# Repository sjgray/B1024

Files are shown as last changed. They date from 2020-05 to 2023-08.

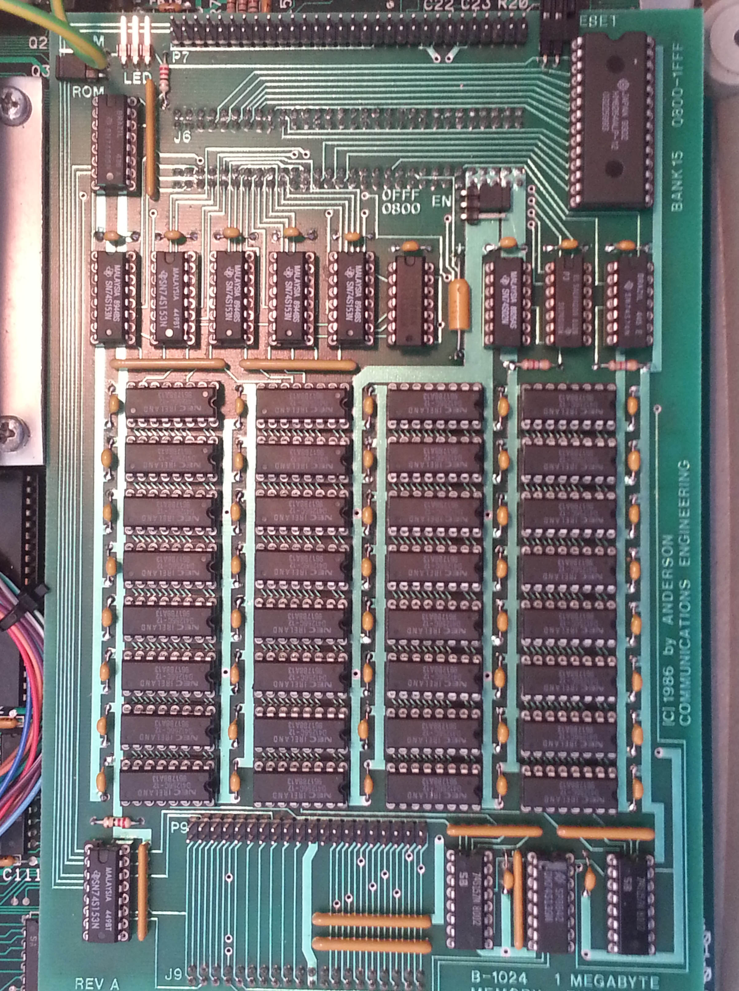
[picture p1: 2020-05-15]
board pics/B1024-Installed.jpg

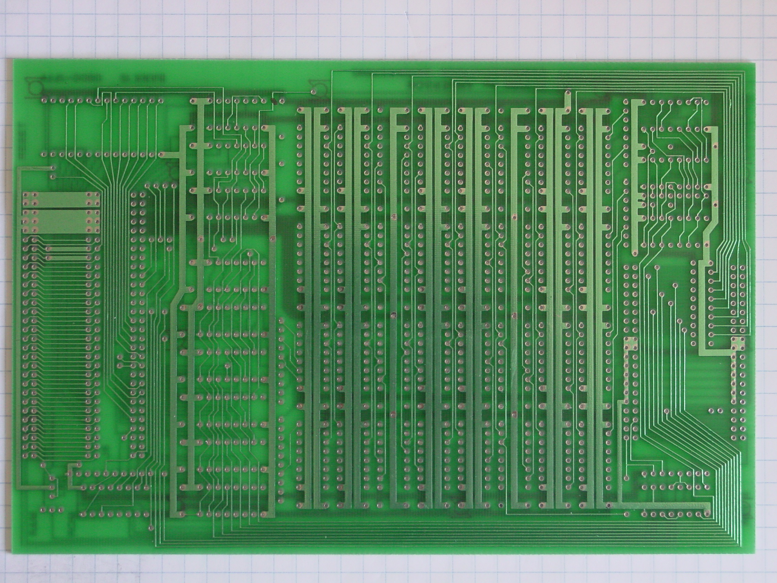
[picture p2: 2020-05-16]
board pics/B1024-Bare-Bottom-mirrored.jpg

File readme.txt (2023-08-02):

B1024 Clone Project (C)2020 Steve J. Gray.
=================== Started May 2020. Updated Aug 2023.

OVERALL STATUS: In Progress

SCHEMATICS    : Currently Reverse engineering Schematic diagram.
BOARD LAYOUT  : Mostly complete
BOARD LABELS  : NONE
GERBERS       : NONE
PCB           : NONE

Intro
-----

This is a project to clone the
Anderson Communication Engineering 1024K Board (Rev A) for CBM-II.

Mike Naberezny purchased a bare board from Bill Degnan and
then scanned it and posted pictures on his web page:

http://mikenaberezny.com/hardware/cbm-ii/b1024-ram-expansion-board/

Thank-you to Mike for providing this information!

Component Reference
-------------------

Since the board has no references for the IC's
I have numbered them based on the following:

- With the board oriented with pin 1's on the LEFT or TOP.
- U1 is at the top left.
- Connectors P7 and J6 are below it
- U2 is at the bottom left.
- U3 to U12 are to the right.

The DRAMs are:
- U12 to U19 on the top row
- U29 to U27
- U28 to U35
- U36 to U43 on the bottom row

Then U44 to U47 on the right of the board
P9 and J9 are between U46 and U47

PARTS LIST
==========

Sockets:
--------
  - 28 pin x 1 for 6264
  - 16 pin x32 for DRAMs
  - 16 pin x11 for other chips
  - 14 pin x 3 for other chips

ICs:
----
U1 - 6264 SRAM, 8Kx8
U2 - 74S85   4-bit Comparator
U3 - 74S74   Dual D positive edge Flip-Flop
U4 - 74S08   Quad 2-input AND
U5 - 74S02   Quad 2-input NOR
U6 - 74LS393 Dual 4-bit Binary Counter
U7 - 74S153  Dual 4 to 1 selector
U8 - 74S153  Dual 4 to 1 selector
U9 - 74S153  Dual 4 to 1 selector
U10- 74S153  Dual 4 to 1 selector
U11- 74S153  Dual 4 to 1 selector

U12 to U43 - 41256 DRAM 256Kx1

U44- 74S157  Quad 2 to 1 Multiplexer
U45- 74S139  Dual 2 to 4 line decoder
U46- 74S157  Quad 2 to 1 Multiplexer
U47- 74S153  Dual 4 to 1 selector

Capacitors:
-----------
C1 to C51 - 0.1uf disc

Resistors:
----------
R1        - 22 ohm
R2, R3    - 4.7K
R4        - 22 ohm

RN1 - 4.7K   SIP 10-pin Bussed   9 Resistor Network
RN2 - 22 ohm SIP 10-pin Separate 5 Resistor Pack
RN3 - 22 ohm SIP 10-pin Separate 5 Resistor Pack
RN4 - 22 ohm SIP 8-pin  Separate 4 Resistor Pack
RN5 - 22 ohm SIP 8-pin  Separate 4 Resistor Pack
RN6 - 4.7K   SIP 8-pin  Bussed   7 Resistor Network
RN7 - 10K    SIP 10-pin Bussed   9 Resistor Network
RN8 - 10K    SIP 10-pin Bussed   9 Resistor Network
RN9 - 4.7K   SIP 8-pin  Bussed   7 Resistor Network

Jumpers/Headers:
----------------
J1 - 2-pin 90 degree male header "RESET" 
J2 - 3-pin 90 degree male header "0FFF/0800 EN"
J3 - 3-pin 90 degree male header "LED"
J4 - 3-pin 90 degree male header "RAM ROM" 
J5 - 60-pin vertical female header 
J6 - 60-pin vertical female header
J9 - 40-pin vertical female headerc
P7 - 60-pin vertical male header
P9 - 40-pin vertical male header

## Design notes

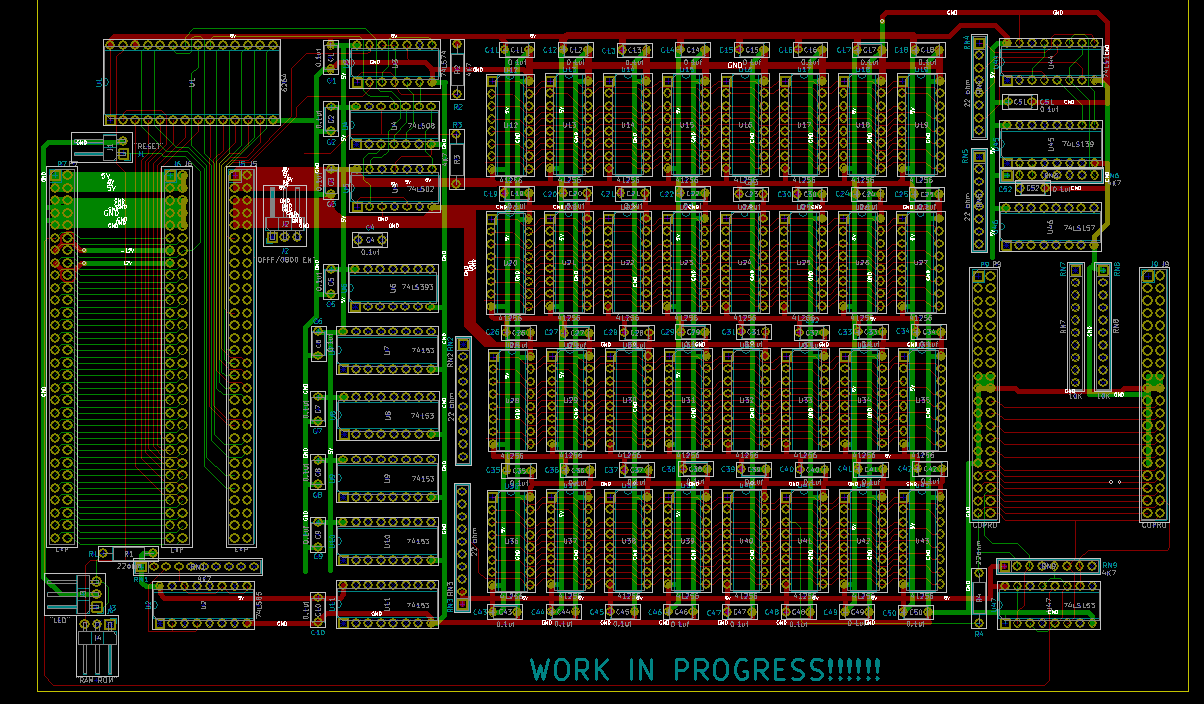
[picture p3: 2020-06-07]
B1024-Kicad Layout.png

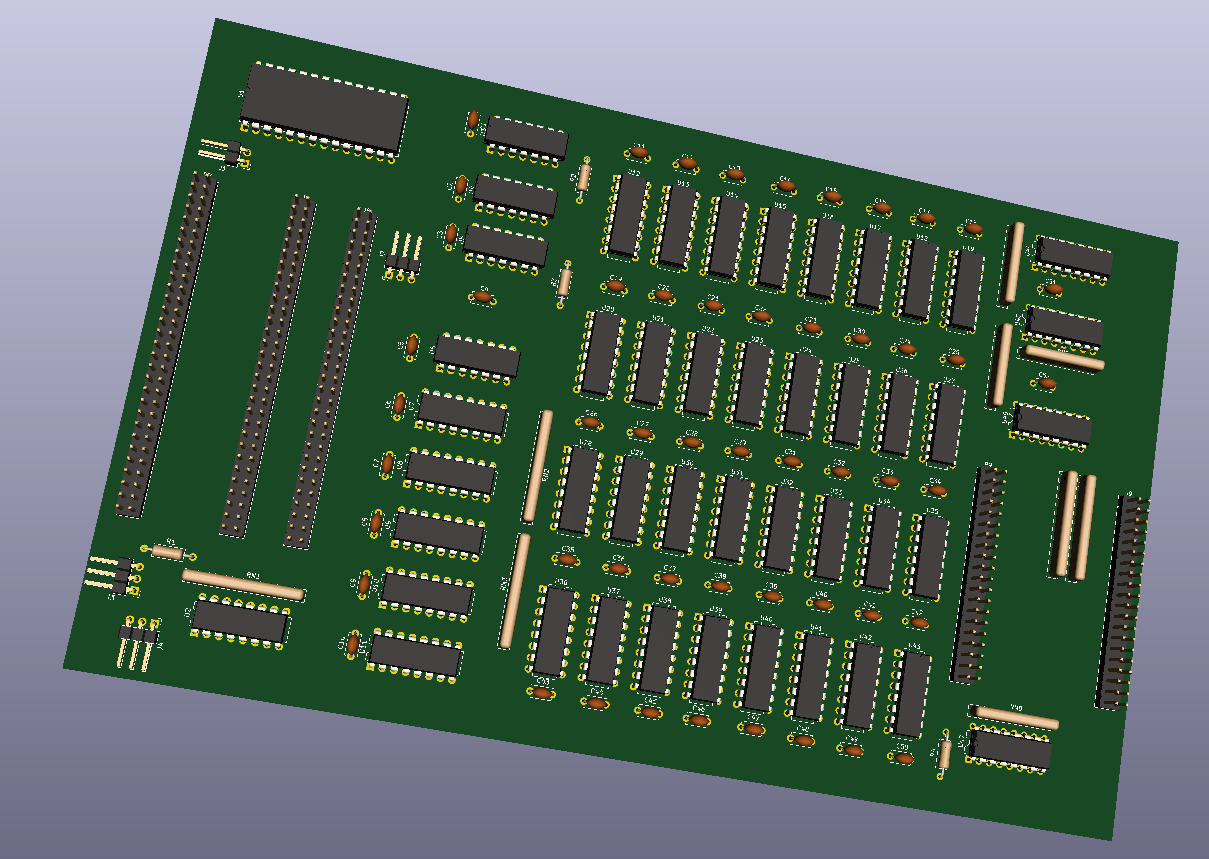
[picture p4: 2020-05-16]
B1024-Kicad Board.png

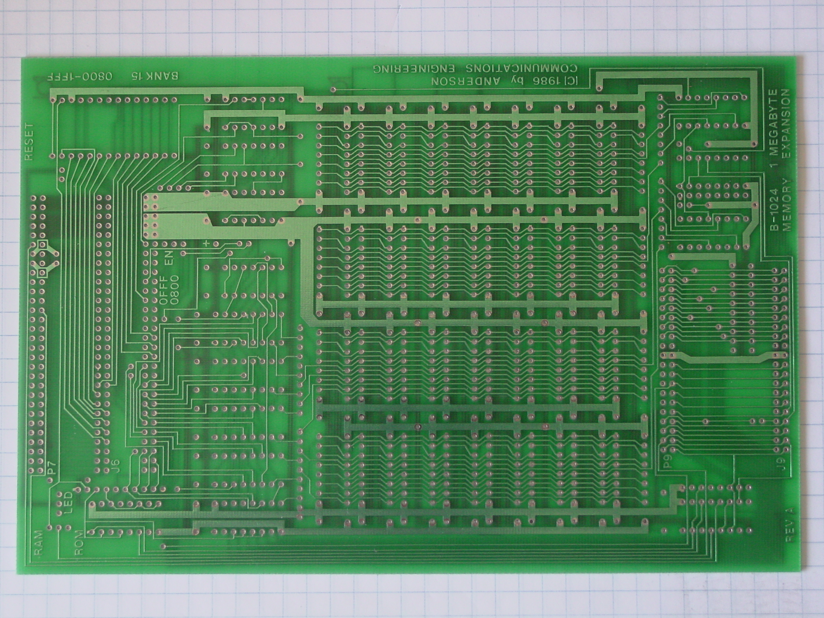
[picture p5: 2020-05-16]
board pics/B1024-Bare-Top.jpg

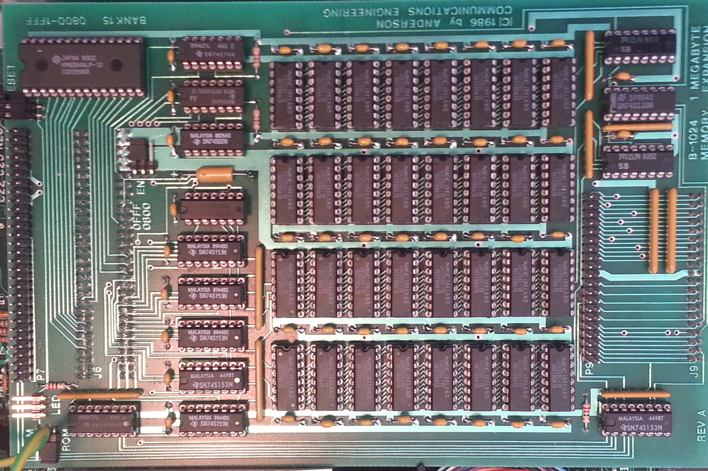
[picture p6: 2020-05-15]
board pics/B1024-Complete.jpg

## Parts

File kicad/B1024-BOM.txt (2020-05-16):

Anderson Communications Engineering B1024 Board for CBM-II
==========================================================
BOM

#01 Circuit Board
#09 Sockets 16-pin x32 for DRAMs
            16-pin x11 for other chips
            14-pin  x3 for other chips
#10 Socket 28-pin x1 for 6264
#11 (Not needed) DIP Plug
#12 Jumper  19141 0.12/ea minimum 10  DONE
#13 41256 DRAM x32  41398  0.69/ea for more than 10  DONE
#14 6264            42892  2.75 DONE
#15 74S02   48266   $0.69  DONE
#16 74S08   48303   $0.69  DONE
#17 74S74   676991  $0.79  DONE
#18 74S85   48952   $1.19  DONE
#19 74S139  ???            DONE
#20 74S153  ???            DONE
#21 74S157  48451   $1.25  DONE
#22 74LS393 47731   $0.85  DONE
#23 0.1uF x51 544921  minimum 10   $0.11 for 100+
#32 4.7K .25W

691024  4.7Kohm .25W
22 ohm 4 section / 8 pin  4608X-2-220LF-ND
22 ohm 5 section / 8 pin  4610X-2-220LF-ND
4.7K 7 section / 8 pin    4608X-1-472LF-ND
4.7K 9 section / 10 pin   4610X-1-472LF-ND
10K 9 section / 10 pin    4610X-1-103LF-ND
10-pin: 5
8-pin: 4

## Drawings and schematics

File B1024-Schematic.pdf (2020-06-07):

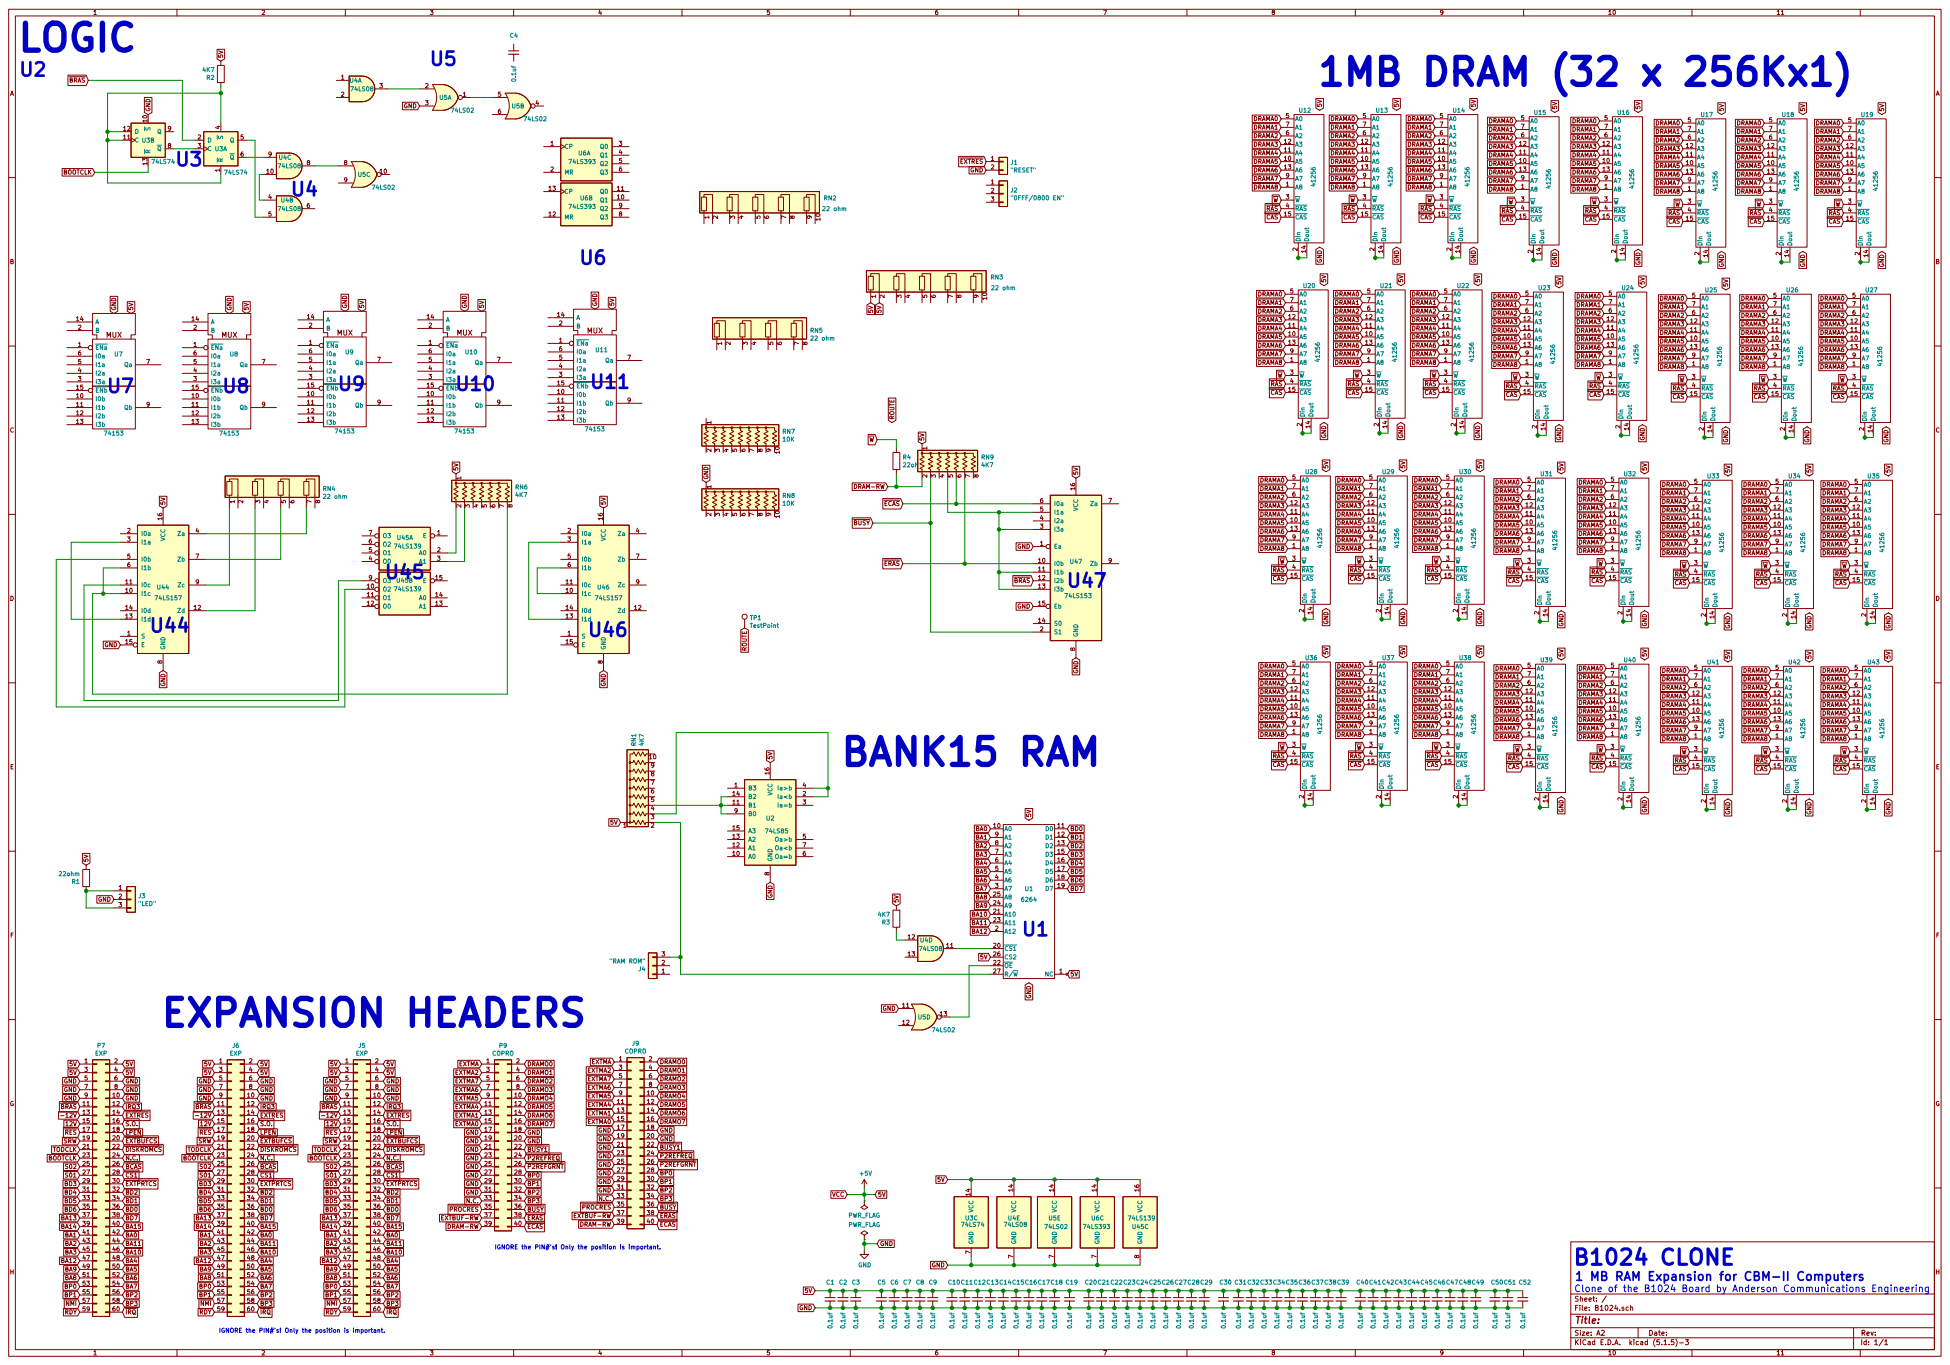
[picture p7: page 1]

DRAMA0 DRAMA1 DRAMA2 DRAMA3 DRAMA4 DRAMA5 DRAMA6 DRAMA7 DRAMA8 RAS CAS DRAMA0 DRAMA4 DRAMA5 DRAMA6 DRAMA7 DRAMA8 RAS CASW

IGNORE the PIN#'s! Only the position is important.

B1024 CLONE
1 MB RAM Expansion for CBM-II Computers
Clone of the B1024 Board by Anderson Communications Engineering

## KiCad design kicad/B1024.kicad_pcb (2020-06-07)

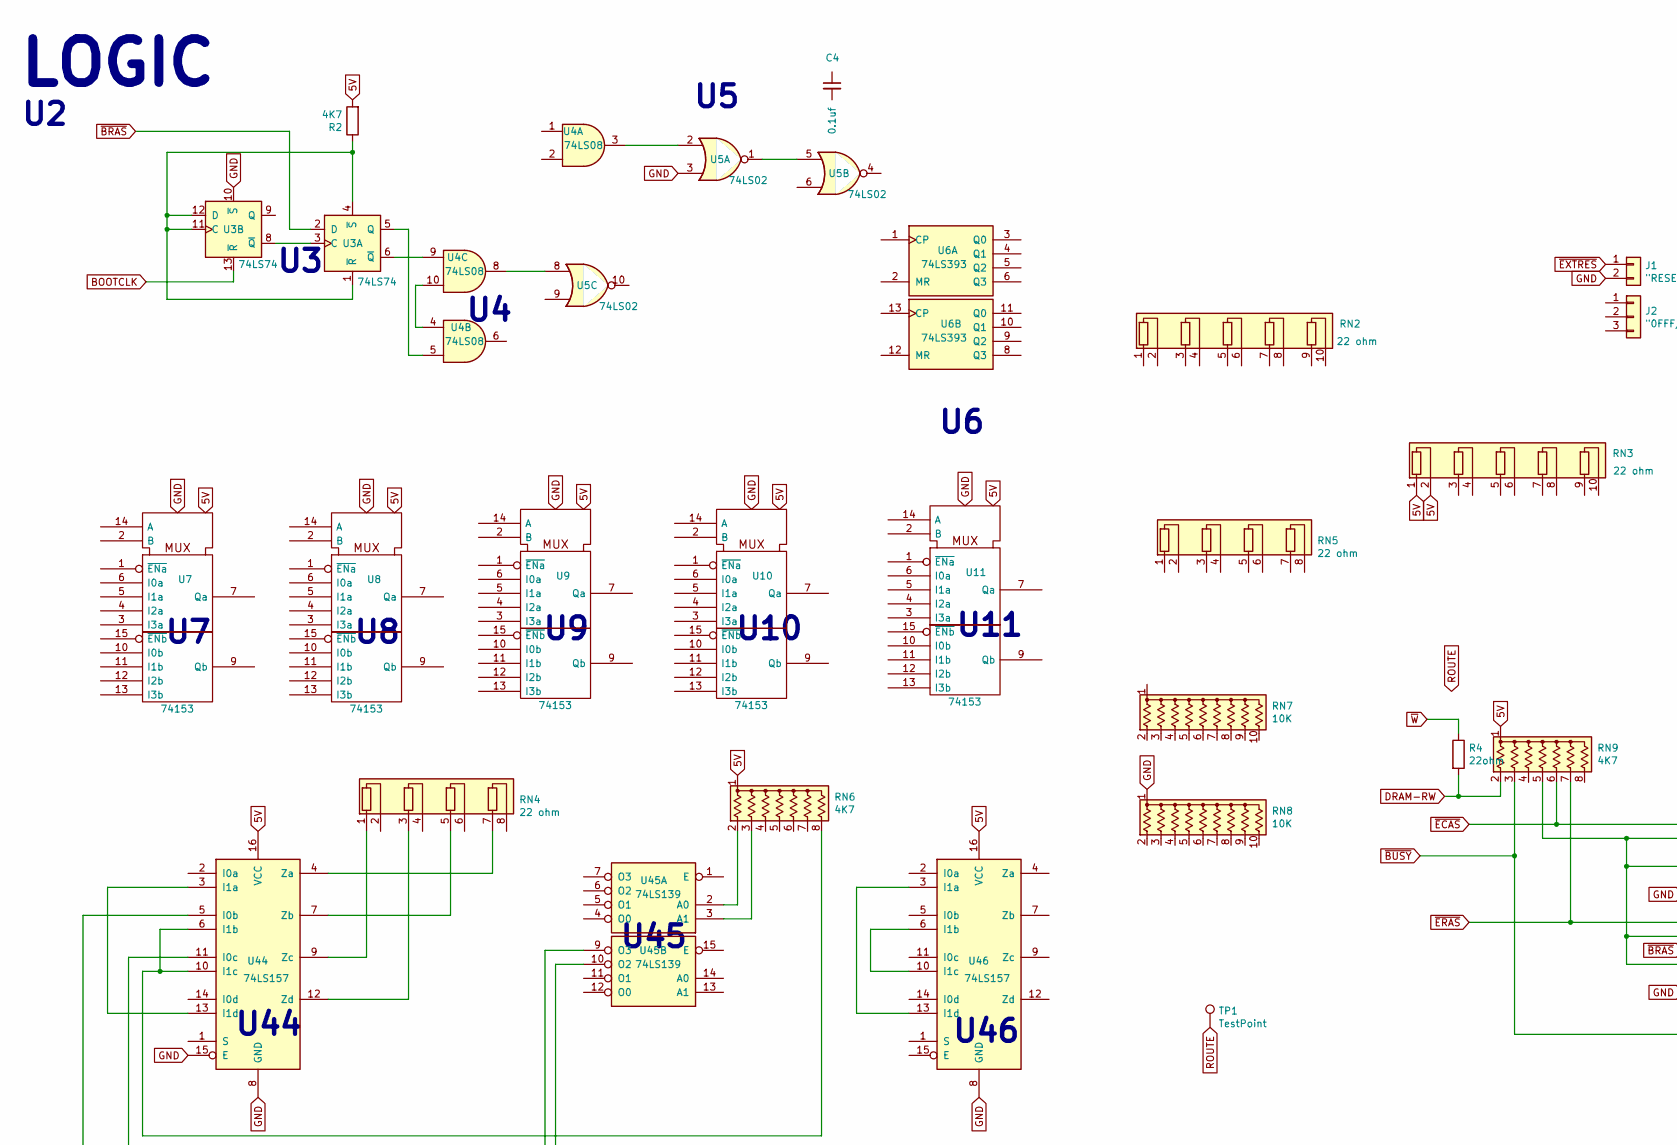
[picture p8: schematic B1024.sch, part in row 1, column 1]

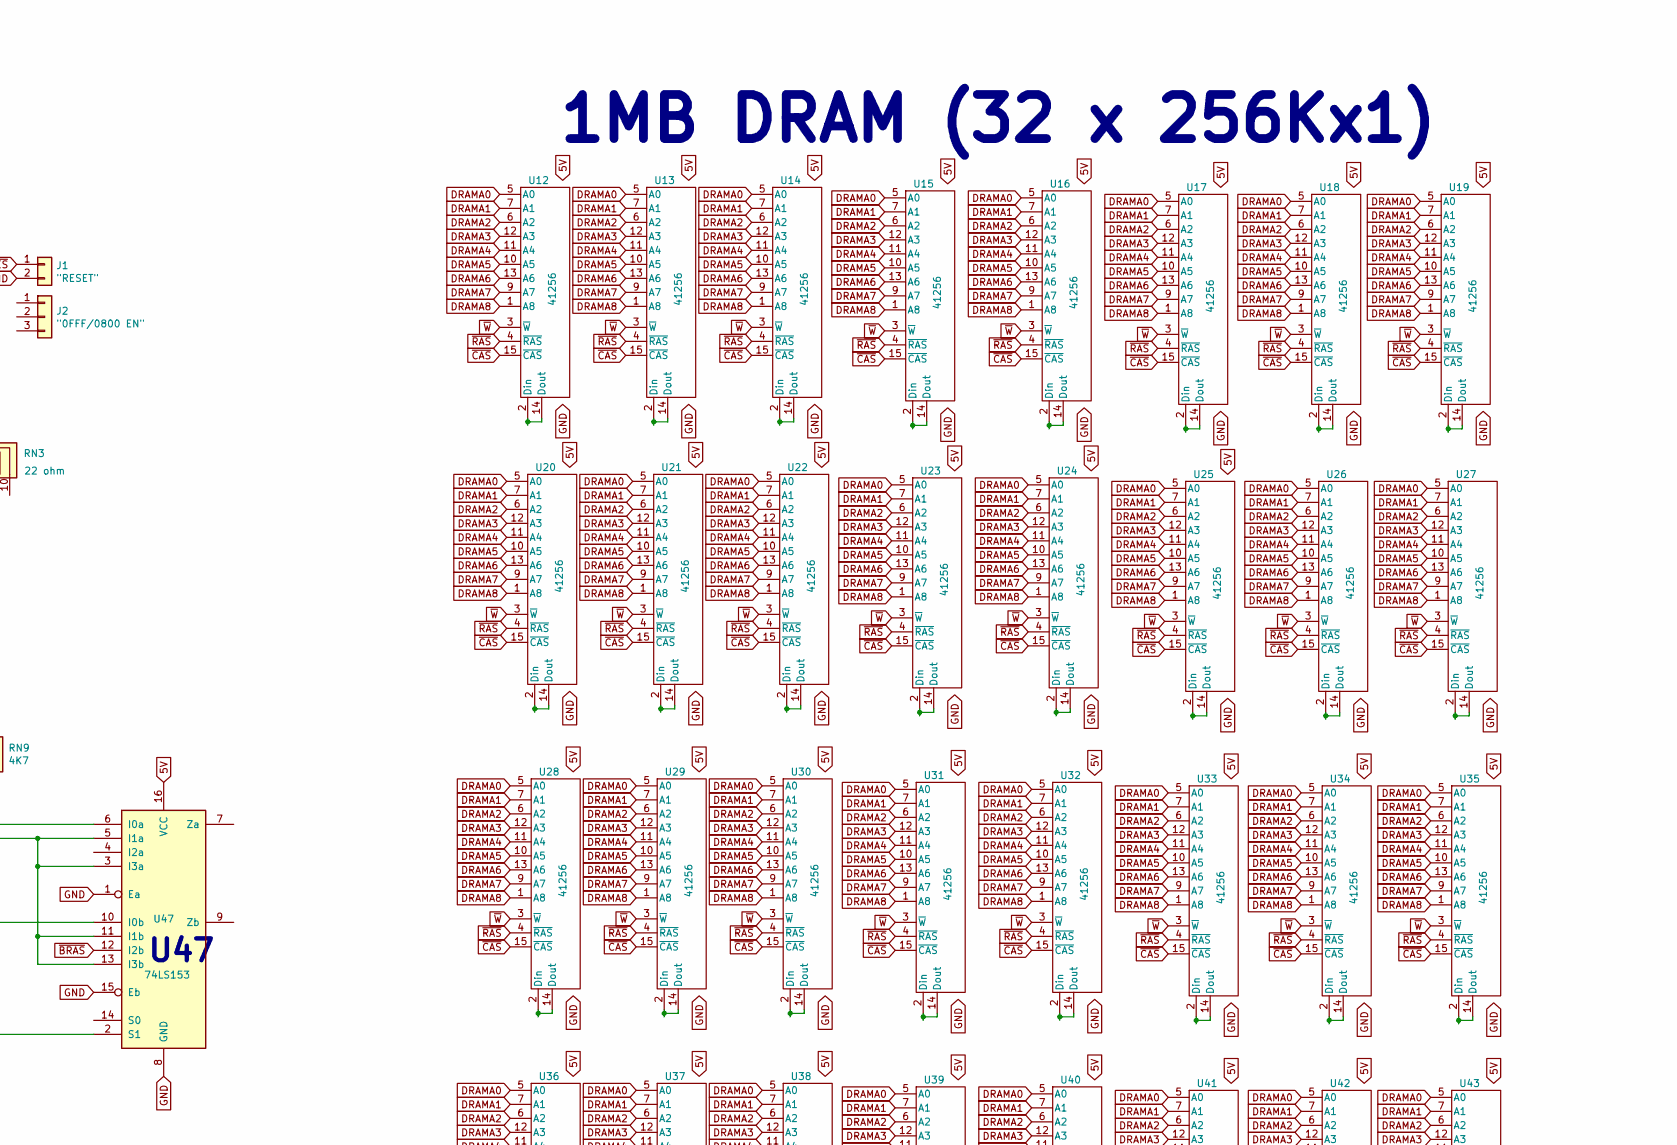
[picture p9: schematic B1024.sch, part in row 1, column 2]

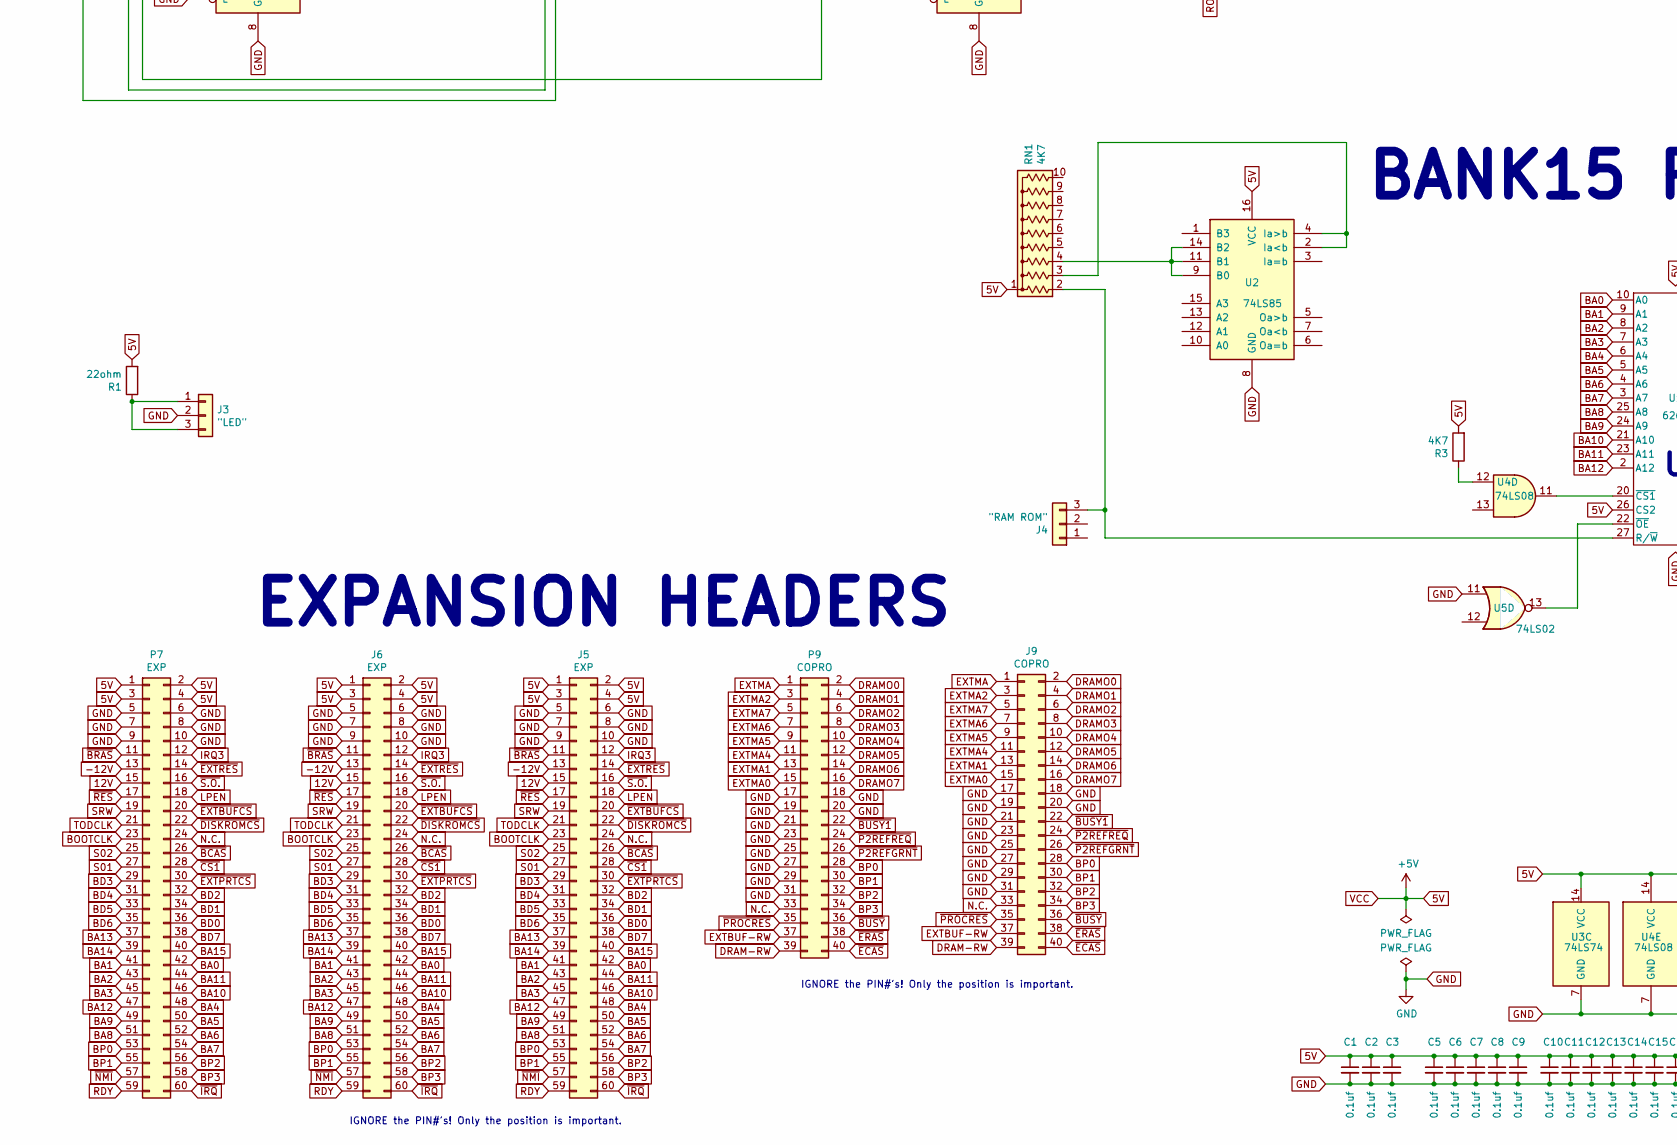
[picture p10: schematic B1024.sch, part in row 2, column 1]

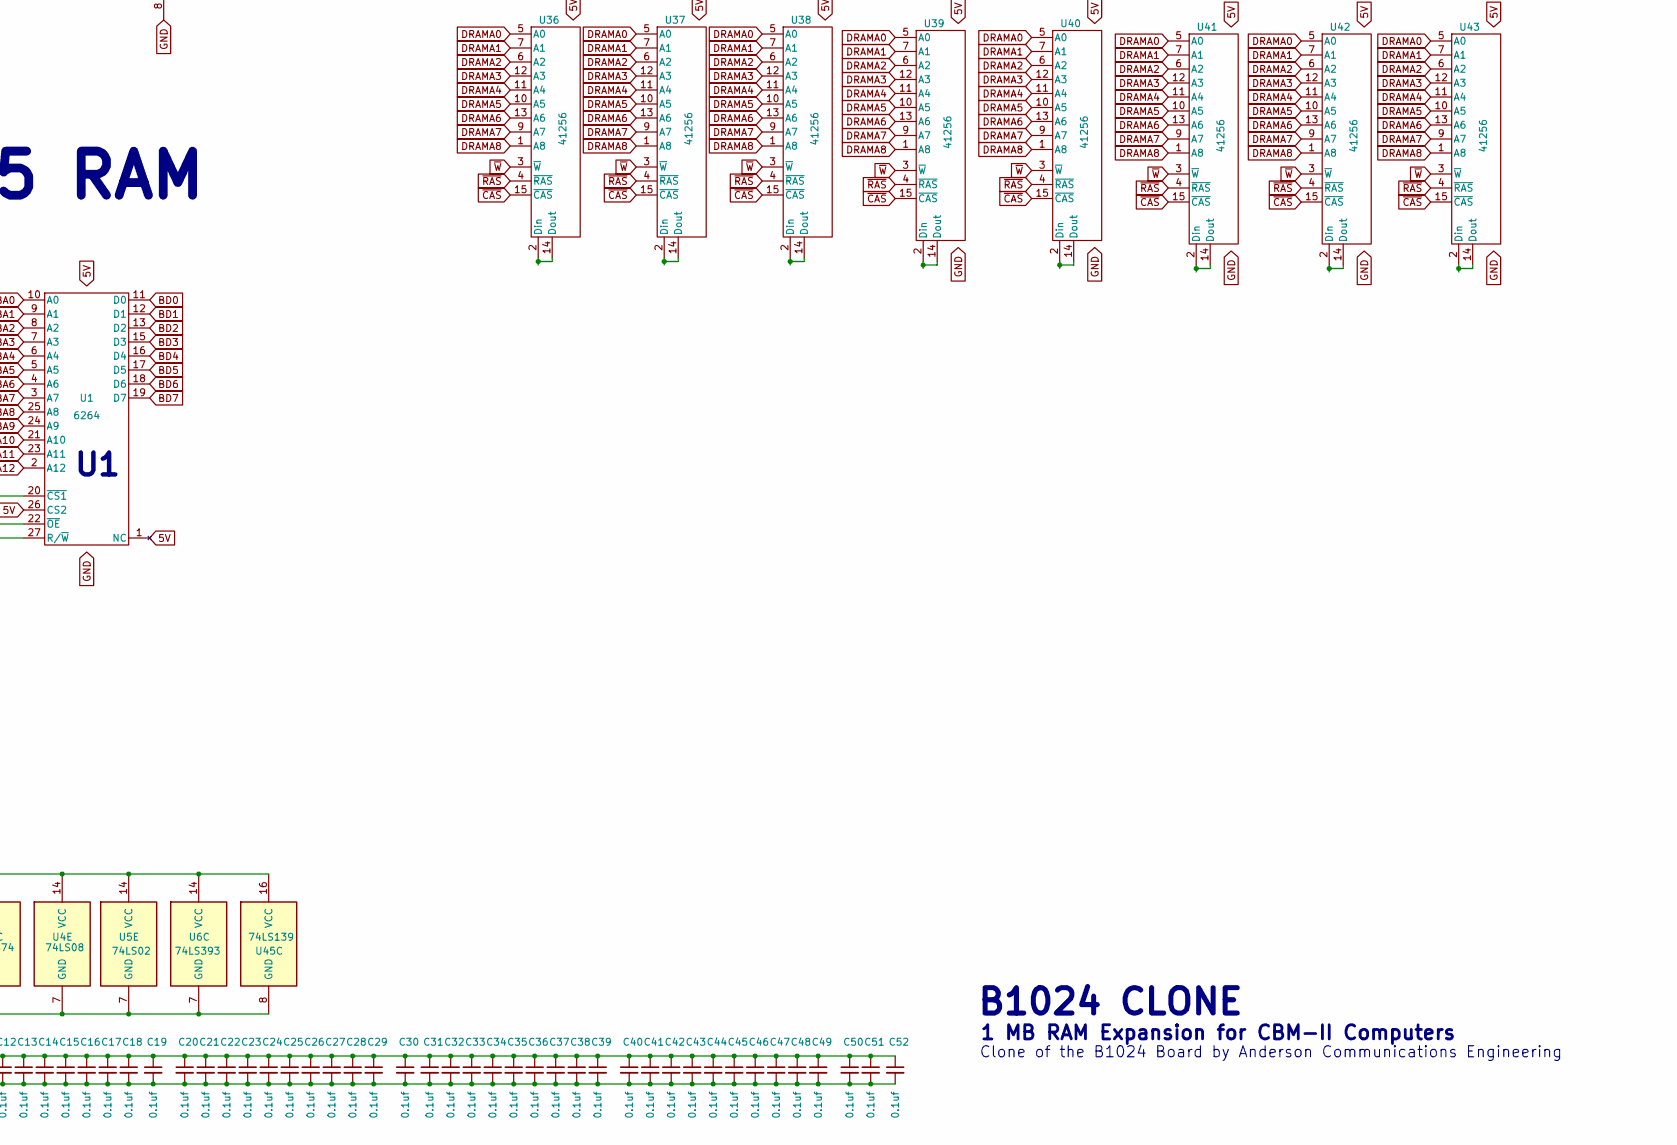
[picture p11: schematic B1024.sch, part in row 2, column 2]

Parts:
C1, C2, C3, C4, C5, C6, C7, C8, C9, C10, C11, C12, C13, C14, C15, C16, C17, C18, C19, C20, C21, C22, C23, C24, C25, C26, C27, C28, C29, C30, C31, C32, C33, C34, C35, C36, C37, C38, C39, C40, C41, C42, C43, C44, C45, C46, C47, C48, C49, C50, C51, C52: 0.1uf; C_Disc_D4.7mm_W2.5mm_P5.00mm
J1: \"RESET\"; PinHeader_1x02_P2.54mm_Horizontal
J2: \"0FFF/0800 EN\"; PinHeader_1x03_P2.54mm_Horizontal
J3: \"LED\"; PinHeader_1x03_P2.54mm_Horizontal
J4: \"RAM ROM\"; PinHeader_1x03_P2.54mm_Horizontal
J5, J6: EXP; PinHeader_2x30_P2.54mm_Vertical
J9: COPRO; PinHeader_2x20_P2.54mm_Vertical
P7: EXP; PinHeader_2x30_P2.54mm_Vertical
P9: COPRO; PinHeader_2x20_P2.54mm_Vertical
R1, R4: 22ohm; R_Axial_DIN0207_L6.3mm_D2.5mm_P10.16mm_Horizontal
R2, R3: 4K7; R_Axial_DIN0207_L6.3mm_D2.5mm_P10.16mm_Horizontal
RN1: 4K7; R_Array_SIP10
RN2, RN3: 22 ohm; R_Array_SIP10
RN4, RN5: 22 ohm; R_Array_SIP8
RN6, RN9: 4K7; R_Array_SIP8
RN7, RN8: 10K; R_Array_SIP10
TP1: TestPoint; PinHeader_1x01_P2.54mm_Vertical
U1: 6264; DIP-28_W15.24mm
U2: 74LS85; DIP-16_W7.62mm
U3: 74LS74; DIP-14_W7.62mm
U4: 74LS08; DIP-14_W7.62mm
U5: 74LS02; DIP-14_W7.62mm
U6: 74LS393; DIP-14_W7.62mm
U7, U8, U9, U10, U11: 74153; DIP-16_W7.62mm
U12, U13, U14, U15, U16, U17, U18, U19, U20, U21, U22, U23, U24, U25, U26, U27, U28, U29, U30, U31, U32, U33, U34, U35, U36, U37, U38, U39, U40, U41, U42, U43: 41256; DIP-16_W7.62mm
U44, U46: 74LS157; DIP-16_W7.62mm
U45: 74LS139; DIP-16_W7.62mm
U47: 74LS153; DIP-16_W7.62mm

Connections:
5V: C1.1, C2.1, C3.1, C5.1, C6.1, C7.1, C8.1, C9.1, C10.1, C11.1, C12.1, C13.1, C14.1, C15.1, C16.1, C17.1, C18.1, C19.1, C20.1, C21.1, C22.1, C23.1, C24.1, C25.1, C26.1, C27.1, C28.1, C29.1, C30.1, C31.1, C32.1, C33.1, C34.1, C35.1, C36.1, C37.1, C38.1, C39.1, C40.1, C41.1, C42.1, C43.1, C44.1, C45.1, C46.1, C47.1, C48.1, C49.1, C50.1, C51.1, C52.1, J5.1, J5.2, J5.3, J5.4, J6.1, J6.2, J6.3, J6.4, P7.1, P7.2, P7.3, P7.4, R1.2, R2.2, R3.2, RN1.1 (common), RN3.1 (R1.1), RN3.2 (R1.2), RN6.1 (common), RN9.1 (common), U1.1 (NC), U1.26 (CS2), U1.28 (Vcc), U2.16 (VCC), U3.14 (VCC), U4.14 (VCC), U5.14 (VCC), U6.14 (VCC), U7.16 (VCC), U8.16 (VCC), U9.16 (VCC), U10.16 (VCC), U11.16 (VCC), U12.8 (Vcc), U13.8 (Vcc), U14.8 (Vcc), U15.8 (Vcc), U16.8 (Vcc), U17.8 (Vcc), U18.8 (Vcc), U19.8 (Vcc), U20.8 (Vcc), U21.8 (Vcc), U22.8 (Vcc), U23.8 (Vcc), U24.8 (Vcc), U25.8 (Vcc), U26.8 (Vcc), U27.8 (Vcc), U28.8 (Vcc), U29.8 (Vcc), U30.8 (Vcc), U31.8 (Vcc), U32.8 (Vcc), U33.8 (Vcc), U34.8 (Vcc), U35.8 (Vcc), U36.8 (Vcc), U37.8 (Vcc), U38.8 (Vcc), U39.8 (Vcc), U40.8 (Vcc), U41.8 (Vcc), U42.8 (Vcc), U43.8 (Vcc), U44.16 (VCC), U45.16 (VCC), U46.16 (VCC), U47.16 (VCC)
12V: J5.15, J6.15, P7.15
-12V: J5.13, J6.13, P7.13
BA0: J5.42, J6.42, P7.42, U1.10 (A0)
BA1: J5.41, J6.41, P7.41, U1.9 (A1)
BA2: J5.43, J6.43, P7.43, U1.8 (A2)
BA3: J5.45, J6.45, P7.45, U1.7 (A3)
BA4: J5.48, J6.48, P7.48, U1.6 (A4)
BA5: J5.50, J6.50, P7.50, U1.5 (A5)
BA6: J5.52, J6.52, P7.52, U1.4 (A6)
BA7: J5.54, J6.54, P7.54, U1.3 (A7)
BA8: J5.51, J6.51, P7.51, U1.25 (A8)
BA9: J5.49, J6.49, P7.49, U1.24 (A9)
BA10: J5.46, J6.46, P7.46, U1.21 (A10)
BA11: J5.44, J6.44, P7.44, U1.23 (A11)
BA12: J5.47, J6.47, P7.47, U1.2 (A12)
BA13: J5.37, J6.37, P7.37
BA14: J5.39, J6.39, P7.39
BA15: J5.40, J6.40, P7.40
BD0: J5.36, J6.36, P7.36, U1.11 (D0)
BD1: J5.34, J6.34, P7.34, U1.12 (D1)
BD2: J5.32, J6.32, P7.32, U1.13 (D2)
BD3: J5.29, J6.29, P7.29, U1.15 (D3)
BD4: J5.31, J6.31, P7.31, U1.16 (D4)
BD5: J5.33, J6.33, P7.33, U1.17 (D5)
BD6: J5.35, J6.35, P7.35, U1.18 (D6)
BD7: J5.38, J6.38, P7.38, U1.19 (D7)
BOOTCLK: J5.23, J6.23, P7.23, U3.13 (~R)
BP0: J5.53, J6.53, J9.28, P7.53, P9.28
BP1: J5.55, J6.55, J9.30, P7.55, P9.30
BP2: J5.56, J6.56, J9.32, P7.56, P9.32
BP3: J5.58, J6.58, J9.34, P7.58, P9.34
DRAM-RW: J9.39, P9.39, R4.2, RN9.2 (R1)
DRAMA0: U12.5 (A0), U13.5 (A0), U14.5 (A0), U15.5 (A0), U16.5 (A0), U17.5 (A0), U18.5 (A0), U19.5 (A0), U20.5 (A0), U21.5 (A0), U22.5 (A0), U23.5 (A0), U24.5 (A0), U25.5 (A0), U26.5 (A0), U27.5 (A0), U28.5 (A0), U29.5 (A0), U30.5 (A0), U31.5 (A0), U32.5 (A0), U33.5 (A0), U34.5 (A0), U35.5 (A0), U36.5 (A0), U37.5 (A0), U38.5 (A0), U39.5 (A0), U40.5 (A0), U41.5 (A0), U42.5 (A0), U43.5 (A0)
DRAMA1: U12.7 (A1), U13.7 (A1), U14.7 (A1), U15.7 (A1), U16.7 (A1), U17.7 (A1), U18.7 (A1), U19.7 (A1), U20.7 (A1), U21.7 (A1), U22.7 (A1), U23.7 (A1), U24.7 (A1), U25.7 (A1), U26.7 (A1), U27.7 (A1), U28.7 (A1), U29.7 (A1), U30.7 (A1), U31.7 (A1), U32.7 (A1), U33.7 (A1), U34.7 (A1), U35.7 (A1), U36.7 (A1), U37.7 (A1), U38.7 (A1), U39.7 (A1), U40.7 (A1), U41.7 (A1), U42.7 (A1), U43.7 (A1)
DRAMA2: U12.6 (A2), U13.6 (A2), U14.6 (A2), U15.6 (A2), U16.6 (A2), U17.6 (A2), U18.6 (A2), U19.6 (A2), U20.6 (A2), U21.6 (A2), U22.6 (A2), U23.6 (A2), U24.6 (A2), U25.6 (A2), U26.6 (A2), U27.6 (A2), U28.6 (A2), U29.6 (A2), U30.6 (A2), U31.6 (A2), U32.6 (A2), U33.6 (A2), U34.6 (A2), U35.6 (A2), U36.6 (A2), U37.6 (A2), U38.6 (A2), U39.6 (A2), U40.6 (A2), U41.6 (A2), U42.6 (A2), U43.6 (A2)
DRAMA3: U12.12 (A3), U13.12 (A3), U14.12 (A3), U15.12 (A3), U16.12 (A3), U17.12 (A3), U18.12 (A3), U19.12 (A3), U20.12 (A3), U21.12 (A3), U22.12 (A3), U23.12 (A3), U24.12 (A3), U25.12 (A3), U26.12 (A3), U27.12 (A3), U28.12 (A3), U29.12 (A3), U30.12 (A3), U31.12 (A3), U32.12 (A3), U33.12 (A3), U34.12 (A3), U35.12 (A3), U36.12 (A3), U37.12 (A3), U38.12 (A3), U39.12 (A3), U40.12 (A3), U41.12 (A3), U42.12 (A3), U43.12 (A3)
DRAMA4: U12.11 (A4), U13.11 (A4), U14.11 (A4), U15.11 (A4), U16.11 (A4), U17.11 (A4), U18.11 (A4), U19.11 (A4), U20.11 (A4), U21.11 (A4), U22.11 (A4), U23.11 (A4), U24.11 (A4), U25.11 (A4), U26.11 (A4), U27.11 (A4), U28.11 (A4), U29.11 (A4), U30.11 (A4), U31.11 (A4), U32.11 (A4), U33.11 (A4), U34.11 (A4), U35.11 (A4), U36.11 (A4), U37.11 (A4), U38.11 (A4), U39.11 (A4), U40.11 (A4), U41.11 (A4), U42.11 (A4), U43.11 (A4)
DRAMA5: U12.10 (A5), U13.10 (A5), U14.10 (A5), U15.10 (A5), U16.10 (A5), U17.10 (A5), U18.10 (A5), U19.10 (A5), U20.10 (A5), U21.10 (A5), U22.10 (A5), U23.10 (A5), U24.10 (A5), U25.10 (A5), U26.10 (A5), U27.10 (A5), U28.10 (A5), U29.10 (A5), U30.10 (A5), U31.10 (A5), U32.10 (A5), U33.10 (A5), U34.10 (A5), U35.10 (A5), U36.10 (A5), U37.10 (A5), U38.10 (A5), U39.10 (A5), U40.10 (A5), U41.10 (A5), U42.10 (A5), U43.10 (A5)
DRAMA6: U12.13 (A6), U13.13 (A6), U14.13 (A6), U15.13 (A6), U16.13 (A6), U17.13 (A6), U18.13 (A6), U19.13 (A6), U20.13 (A6), U21.13 (A6), U22.13 (A6), U23.13 (A6), U24.13 (A6), U25.13 (A6), U26.13 (A6), U27.13 (A6), U28.13 (A6), U29.13 (A6), U30.13 (A6), U31.13 (A6), U32.13 (A6), U33.13 (A6), U34.13 (A6), U35.13 (A6), U36.13 (A6), U37.13 (A6), U38.13 (A6), U39.13 (A6), U40.13 (A6), U41.13 (A6), U42.13 (A6), U43.13 (A6)
DRAMA7: U12.9 (A7), U13.9 (A7), U14.9 (A7), U15.9 (A7), U16.9 (A7), U17.9 (A7), U18.9 (A7), U19.9 (A7), U20.9 (A7), U21.9 (A7), U22.9 (A7), U23.9 (A7), U24.9 (A7), U25.9 (A7), U26.9 (A7), U27.9 (A7), U28.9 (A7), U29.9 (A7), U30.9 (A7), U31.9 (A7), U32.9 (A7), U33.9 (A7), U34.9 (A7), U35.9 (A7), U36.9 (A7), U37.9 (A7), U38.9 (A7), U39.9 (A7), U40.9 (A7), U41.9 (A7), U42.9 (A7), U43.9 (A7)
DRAMA8: U12.1 (A8), U13.1 (A8), U14.1 (A8), U15.1 (A8), U16.1 (A8), U17.1 (A8), U18.1 (A8), U19.1 (A8), U20.1 (A8), U21.1 (A8), U22.1 (A8), U23.1 (A8), U24.1 (A8), U25.1 (A8), U26.1 (A8), U27.1 (A8), U28.1 (A8), U29.1 (A8), U30.1 (A8), U31.1 (A8), U32.1 (A8), U33.1 (A8), U34.1 (A8), U35.1 (A8), U36.1 (A8), U37.1 (A8), U38.1 (A8), U39.1 (A8), U40.1 (A8), U41.1 (A8), U42.1 (A8), U43.1 (A8)
DRAMO0: J9.2, P9.2
DRAMO1: J9.4, P9.4
DRAMO2: J9.6, P9.6
DRAMO3: J9.8, P9.8
DRAMO4: J9.10, P9.10
DRAMO5: J9.12, P9.12
DRAMO6: J9.14, P9.14
DRAMO7: J9.16, P9.16
EXTBUF-RW: J9.37, P9.37
EXTMA: J9.1, P9.1
EXTMA0: J9.15, P9.15
EXTMA1: J9.13, P9.13
EXTMA2: J9.3, P9.3
EXTMA4: J9.11, P9.11
EXTMA5: J9.9, P9.9
EXTMA6: J9.7, P9.7
EXTMA7: J9.5, P9.5
GND: C1.2, C2.2, C3.2, C5.2, C6.2, C7.2, C8.2, C9.2, C10.2, C11.2, C12.2, C13.2, C14.2, C15.2, C16.2, C17.2, C18.2, C19.2, C20.2, C21.2, C22.2, C23.2, C24.2, C25.2, C26.2, C27.2, C28.2, C29.2, C30.2, C31.2, C32.2, C33.2, C34.2, C35.2, C36.2, C37.2, C38.2, C39.2, C40.2, C41.2, C42.2, C43.2, C44.2, C45.2, C46.2, C47.2, C48.2, C49.2, C50.2, C51.2, C52.2, J1.2, J3.2, J5.5, J5.6, J5.7, J5.8, J5.9, J5.10, J6.5, J6.6, J6.7, J6.8, J6.9, J6.10, J9.17, J9.18, J9.19, J9.20, J9.21, J9.23, J9.25, J9.27, J9.29, J9.31, P7.5, P7.6, P7.7, P7.8, P7.9, P7.10, P9.17, P9.18, P9.19, P9.20, P9.21, P9.23, P9.25, P9.27, P9.29, P9.31, RN8.1 (common), U1.14 (GND), U2.8 (GND), U3.7 (GND), U3.10 (~S), U4.7 (GND), U5.3, U5.7 (GND), U5.11, U6.7 (GND), U7.8 (GND), U8.8 (GND), U9.8 (GND), U10.8 (GND), U11.8 (GND), U12.16 (GND), U13.16 (GND), U14.16 (GND), U15.16 (GND), U16.16 (GND), U17.16 (GND), U18.16 (GND), U19.16 (GND), U20.16 (GND), U21.16 (GND), U22.16 (GND), U23.16 (GND), U24.16 (GND), U25.16 (GND), U26.16 (GND), U27.16 (GND), U28.16 (GND), U29.16 (GND), U30.16 (GND), U31.16 (GND), U32.16 (GND), U33.16 (GND), U34.16 (GND), U35.16 (GND), U36.16 (GND), U37.16 (GND), U38.16 (GND), U39.16 (GND), U40.16 (GND), U41.16 (GND), U42.16 (GND), U43.16 (GND), U44.8 (GND), U44.15 (E), U45.8 (GND), U46.8 (GND), U47.1 (Ea), U47.8 (GND), U47.15 (Eb)
IRQ3: J5.12, J6.12, P7.12
LPEN: J5.18, J6.18, P7.18
N.C.: J5.24, J6.24, J9.33, P7.24, P9.33
unnamed: J3.1, J3.3, R1.1
unnamed: J4.3, RN1.2 (R1), U1.27 (R/~W)
unnamed: R2.1, U3.1 (~R), U3.4 (~S), U3.11 (C), U3.12 (D)
unnamed: R3.1, U4.12
unnamed: RN1.3 (R2), U2.2 (Ia<b), U2.4 (Ia>b)
unnamed: RN1.4 (R3), U2.9 (B0), U2.11 (B1), U2.14 (B2)
unnamed: RN4.1 (R1.1), U44.9 (Zc)
unnamed: RN4.3 (R2.1), U44.12 (Zd)
unnamed: RN4.5 (R3.1), U44.7 (Zb)
unnamed: RN4.7 (R4.1), U44.4 (Za)
unnamed: RN6.2 (R1), U45.2 (A0)
unnamed: RN6.3 (R2), U45.3 (A1)
unnamed: RN6.8 (R7), U44.6 (I1b), U44.10 (I1c)
unnamed: RN9.5 (R4), U47.3 (I3a), U47.5 (I1a), U47.11 (I1b), U47.13 (I3b)
unnamed: U1.20 (~CS1), U4.11
unnamed: U1.22 (~OE), U5.13
unnamed: U3.3 (C), U3.8 (~Q)
unnamed: U3.5 (Q), U4.5
unnamed: U3.6 (~Q), U4.9
unnamed: U4.3, U5.2
unnamed: U4.8, U5.8
unnamed: U4.4, U4.10
unnamed: U5.1, U5.5
unnamed: U12.2 (Din), U12.14 (Dout)
unnamed: U13.2 (Din), U13.14 (Dout)
unnamed: U14.2 (Din), U14.14 (Dout)
unnamed: U15.2 (Din), U15.14 (Dout)
unnamed: U16.2 (Din), U16.14 (Dout)
unnamed: U17.2 (Din), U17.14 (Dout)
unnamed: U18.2 (Din), U18.14 (Dout)
unnamed: U19.2 (Din), U19.14 (Dout)
unnamed: U20.2 (Din), U20.14 (Dout)
unnamed: U21.2 (Din), U21.14 (Dout)
unnamed: U22.2 (Din), U22.14 (Dout)
unnamed: U23.2 (Din), U23.14 (Dout)
unnamed: U24.2 (Din), U24.14 (Dout)
unnamed: U25.2 (Din), U25.14 (Dout)
unnamed: U26.2 (Din), U26.14 (Dout)
unnamed: U27.2 (Din), U27.14 (Dout)
unnamed: U28.2 (Din), U28.14 (Dout)
unnamed: U29.2 (Din), U29.14 (Dout)
unnamed: U30.2 (Din), U30.14 (Dout)
unnamed: U31.2 (Din), U31.14 (Dout)
unnamed: U32.2 (Din), U32.14 (Dout)
unnamed: U33.2 (Din), U33.14 (Dout)
unnamed: U34.2 (Din), U34.14 (Dout)
unnamed: U35.2 (Din), U35.14 (Dout)
unnamed: U36.2 (Din), U36.14 (Dout)
unnamed: U37.2 (Din), U37.14 (Dout)
unnamed: U38.2 (Din), U38.14 (Dout)
unnamed: U39.2 (Din), U39.14 (Dout)
unnamed: U40.2 (Din), U40.14 (Dout)
unnamed: U41.2 (Din), U41.14 (Dout)
unnamed: U42.2 (Din), U42.14 (Dout)
unnamed: U43.2 (Din), U43.14 (Dout)
unnamed: U44.5 (I0b), U45.10 (O2)
unnamed: U44.11 (I0c), U45.9 (O3)
unnamed: U44.3 (I1a), U44.13 (I1d)
unnamed: U46.6 (I1b), U46.10 (I1c)
unnamed: U46.3 (I1a), U46.13 (I1d)
RDY: J5.59, J6.59, P7.59
S01: J5.27, J6.27, P7.27
S02: J5.25, J6.25, P7.25
SRW: J5.19, J6.19, P7.19
TODCLK: J5.21, J6.21, P7.21
~BCAS: J5.26, J6.26, P7.26
~BRAS: J5.11, J6.11, P7.11, U3.2 (D), U47.12 (I2b)
~BUSY: J9.36, P9.36, RN9.3 (R2), U47.2 (S1)
~BUSY1: J9.22, P9.22
~CAS: U12.15 (~CAS), U13.15 (~CAS), U14.15 (~CAS), U15.15 (~CAS), U16.15 (~CAS), U17.15 (~CAS), U18.15 (~CAS), U19.15 (~CAS), U20.15 (~CAS), U21.15 (~CAS), U22.15 (~CAS), U23.15 (~CAS), U24.15 (~CAS), U25.15 (~CAS), U26.15 (~CAS), U27.15 (~CAS), U28.15 (~CAS), U29.15 (~CAS), U30.15 (~CAS), U31.15 (~CAS), U32.15 (~CAS), U33.15 (~CAS), U34.15 (~CAS), U35.15 (~CAS), U36.15 (~CAS), U37.15 (~CAS), U38.15 (~CAS), U39.15 (~CAS), U40.15 (~CAS), U41.15 (~CAS), U42.15 (~CAS), U43.15 (~CAS)
~CS1: J5.28, J6.28, P7.28
~DISKROMCS: J5.22, J6.22, P7.22
~ECAS: J9.40, P9.40, RN9.6 (R5), U47.6 (I0a)
~ERAS: J9.38, P9.38, RN9.7 (R6), U47.10 (I0b)
~EXTBUFCS: J5.20, J6.20, P7.20
~EXTPRTCS: J5.30, J6.30, P7.30
~EXTRES: J1.1, J5.14, J6.14, P7.14
~IRQ: J5.60, J6.60, P7.60
~NMI: J5.57, J6.57, P7.57
~P2REFGRNT: J9.26, P9.26
~P2REFREQ: J9.24, P9.24
~PROCRES: J9.35, P9.35
~RAS: U12.4 (~RAS), U13.4 (~RAS), U14.4 (~RAS), U15.4 (~RAS), U16.4 (~RAS), U17.4 (~RAS), U18.4 (~RAS), U19.4 (~RAS), U20.4 (~RAS), U21.4 (~RAS), U22.4 (~RAS), U23.4 (~RAS), U24.4 (~RAS), U25.4 (~RAS), U26.4 (~RAS), U27.4 (~RAS), U28.4 (~RAS), U29.4 (~RAS), U30.4 (~RAS), U31.4 (~RAS), U32.4 (~RAS), U33.4 (~RAS), U34.4 (~RAS), U35.4 (~RAS), U36.4 (~RAS), U37.4 (~RAS), U38.4 (~RAS), U39.4 (~RAS), U40.4 (~RAS), U41.4 (~RAS), U42.4 (~RAS), U43.4 (~RAS)
~RES: J5.17, J6.17, P7.17
~S.O.: J5.16, J6.16, P7.16
~W: R4.1, U12.3 (~W), U13.3 (~W), U14.3 (~W), U15.3 (~W), U16.3 (~W), U17.3 (~W), U18.3 (~W), U19.3 (~W), U20.3 (~W), U21.3 (~W), U22.3 (~W), U23.3 (~W), U24.3 (~W), U25.3 (~W), U26.3 (~W), U27.3 (~W), U28.3 (~W), U29.3 (~W), U30.3 (~W), U31.3 (~W), U32.3 (~W), U33.3 (~W), U34.3 (~W), U35.3 (~W), U36.3 (~W), U37.3 (~W), U38.3 (~W), U39.3 (~W), U40.3 (~W), U41.3 (~W), U42.3 (~W), U43.3 (~W)

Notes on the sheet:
1MB DRAM (32 x 256Kx1)
B1024 CLONE
EXPANSION HEADERS
BANK15 RAM
1 MB RAM Expansion for CBM-II Computers
Clone of the B1024 Board by Anderson Communications Engineering
LOGIC
U44
U45
U46
U47
U10
U11
IGNORE the PIN#'s! Only the position is important.

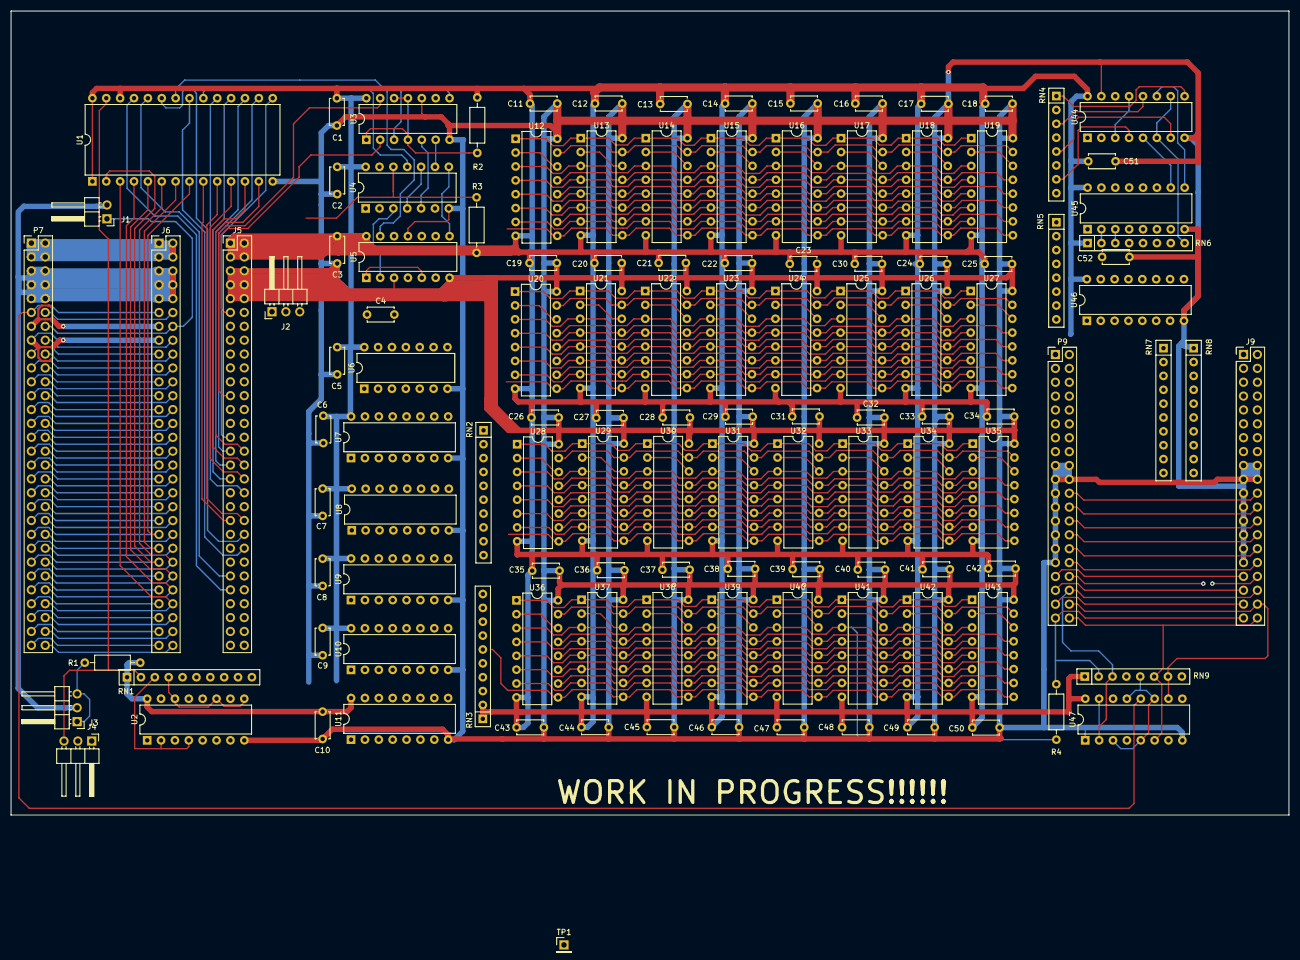
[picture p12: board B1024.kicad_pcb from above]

Board: 2 copper layers, 234.0 x 147.2 mm, 122 parts (0 on the bottom side), 149 nets.

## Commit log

2020-05-15 Initial upload
    Includes pics, bom, and kicad files. Work in progress!
    [B1024.kicad_pcb, B1024.sch]
2020-05-16 Add remaining parts, prelim board layout
    Rotated pictures to match board layout. Added missing ics, resistors,
    and jumpers. Preliminary layout. Updated readme.
    [B1024.kicad_pcb, B1024.sch]
2020-05-16 Fix readme text. Add current progress pics
    Fix spelling mistakes in readme. Add schematic, board layout and board
    render pictures of current progress.
2020-05-25 Updated board layout with measurements
    Add measurement for port spacing
    [B1024.kicad_pcb, B1024.sch]
2020-06-07 Routing and circuit updates
    Schematic is starting to take shape. Route most common dram line and
    many expansion lines.
    [B1024.kicad_pcb, B1024.sch]
2020-06-07 Updated progress pics
    pcb and schematic pics
